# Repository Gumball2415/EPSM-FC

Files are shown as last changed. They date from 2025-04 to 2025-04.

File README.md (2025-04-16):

# EPSM-FC

Expansion Port Sound Module for the Famicom

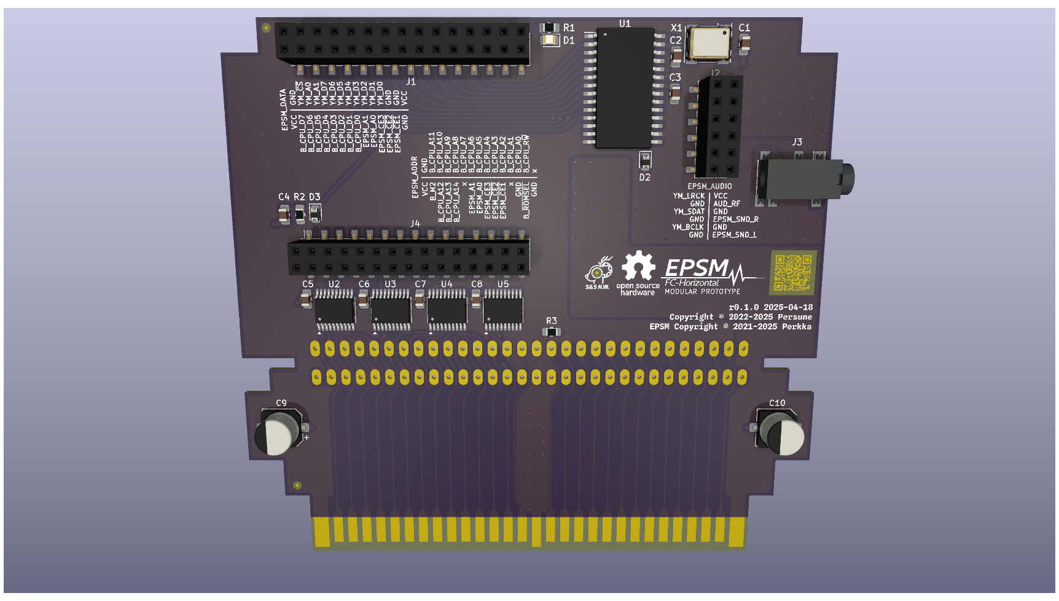
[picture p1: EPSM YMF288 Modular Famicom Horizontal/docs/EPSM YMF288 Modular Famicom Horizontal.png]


## About

Work in progress!!

This is a version of the EPSM ported for use with the Famicom.

The challenge with the Famicom version is that the device no longer has access
to the extra control signals on the NES expansion port. Most relevant, OUT1,
CPU_A15, and all the EXP pins. This project aims to solve this using extra logic
that can recreate the necessary signals for addressing the EPSM.

## License

This design is licensed under the TAPR Open Hardware License.\
For resale, please contact Pierre Althinsson (Perkka).

Original EPSM is Copyright (C) 2021-2025 Pierre Althinson.\
EPSM-FC is Copyright (C) 2022-2025 Persune.

## Usage

- [NESDev wiki](https://www.nesdev.org/wiki/Expansion_Port_Sound_Module)
- Also see [the original EPSM repo](https://github.com/Perkka2/EPSM/)

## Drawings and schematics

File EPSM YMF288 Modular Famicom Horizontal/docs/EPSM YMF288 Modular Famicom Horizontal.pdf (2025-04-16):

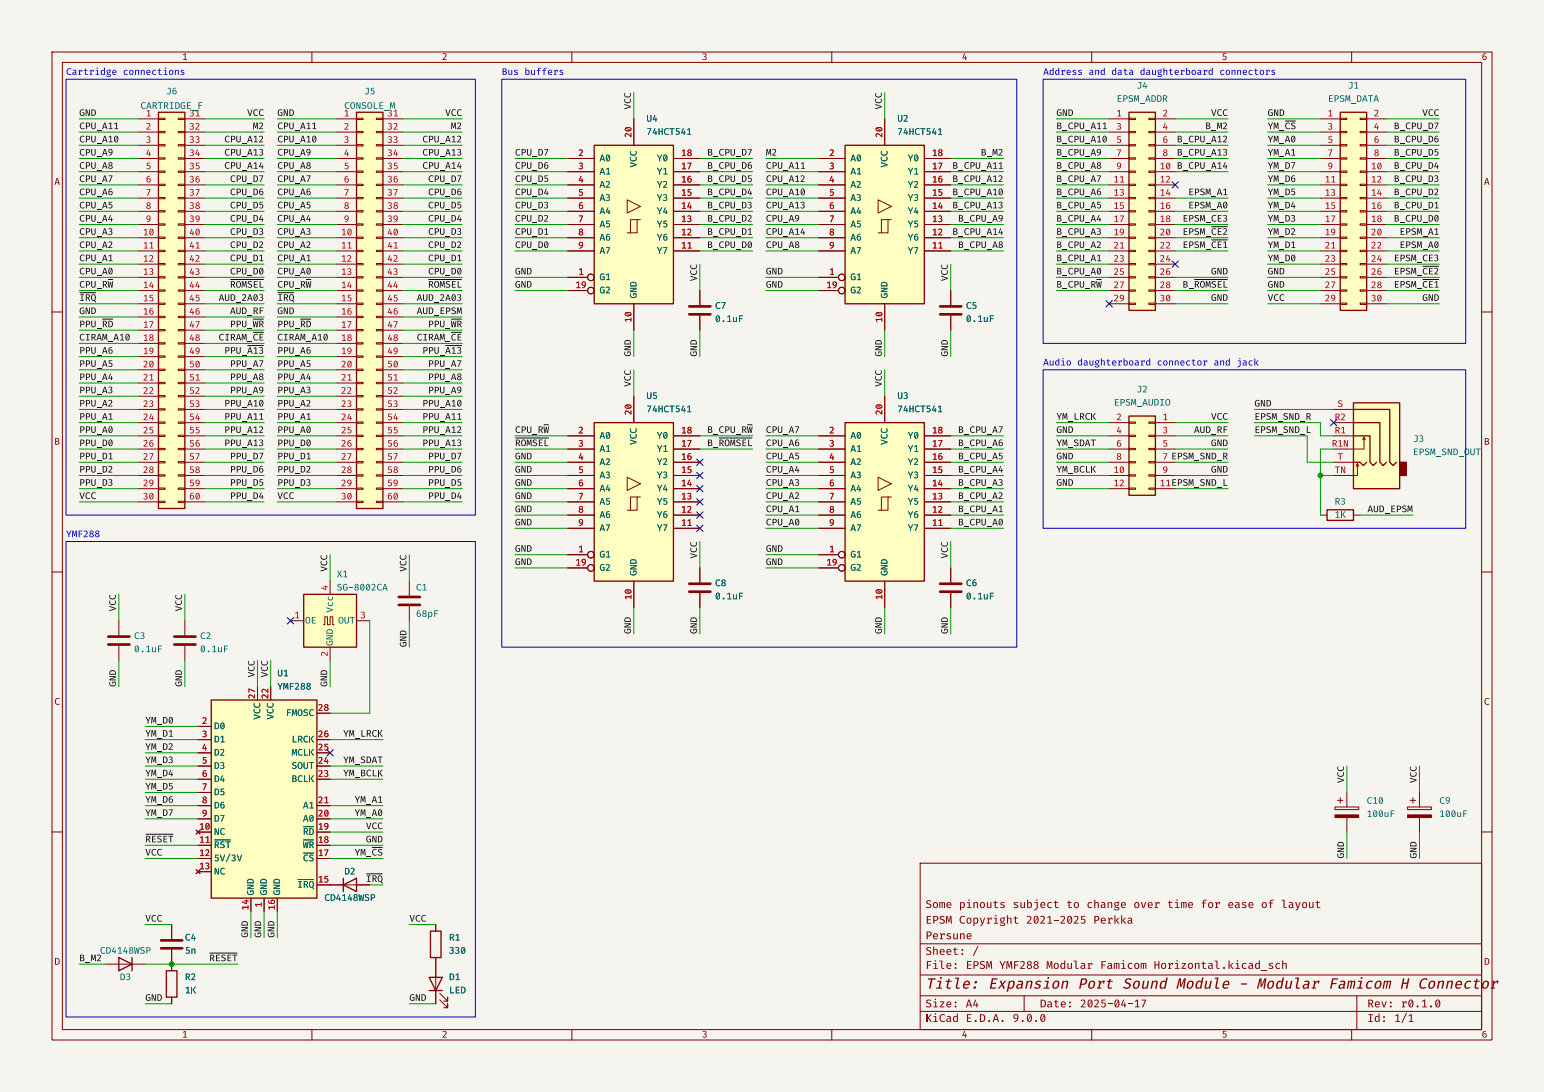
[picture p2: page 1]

20 ~{RD} 19 ~{WR} 18 ~{CS} 17 ~{IRQ}15 D0
YM_D4 YM_D5 YM_D2 YM_D3 VCC
~{RESET} YM_D6 YM_D7 VCC

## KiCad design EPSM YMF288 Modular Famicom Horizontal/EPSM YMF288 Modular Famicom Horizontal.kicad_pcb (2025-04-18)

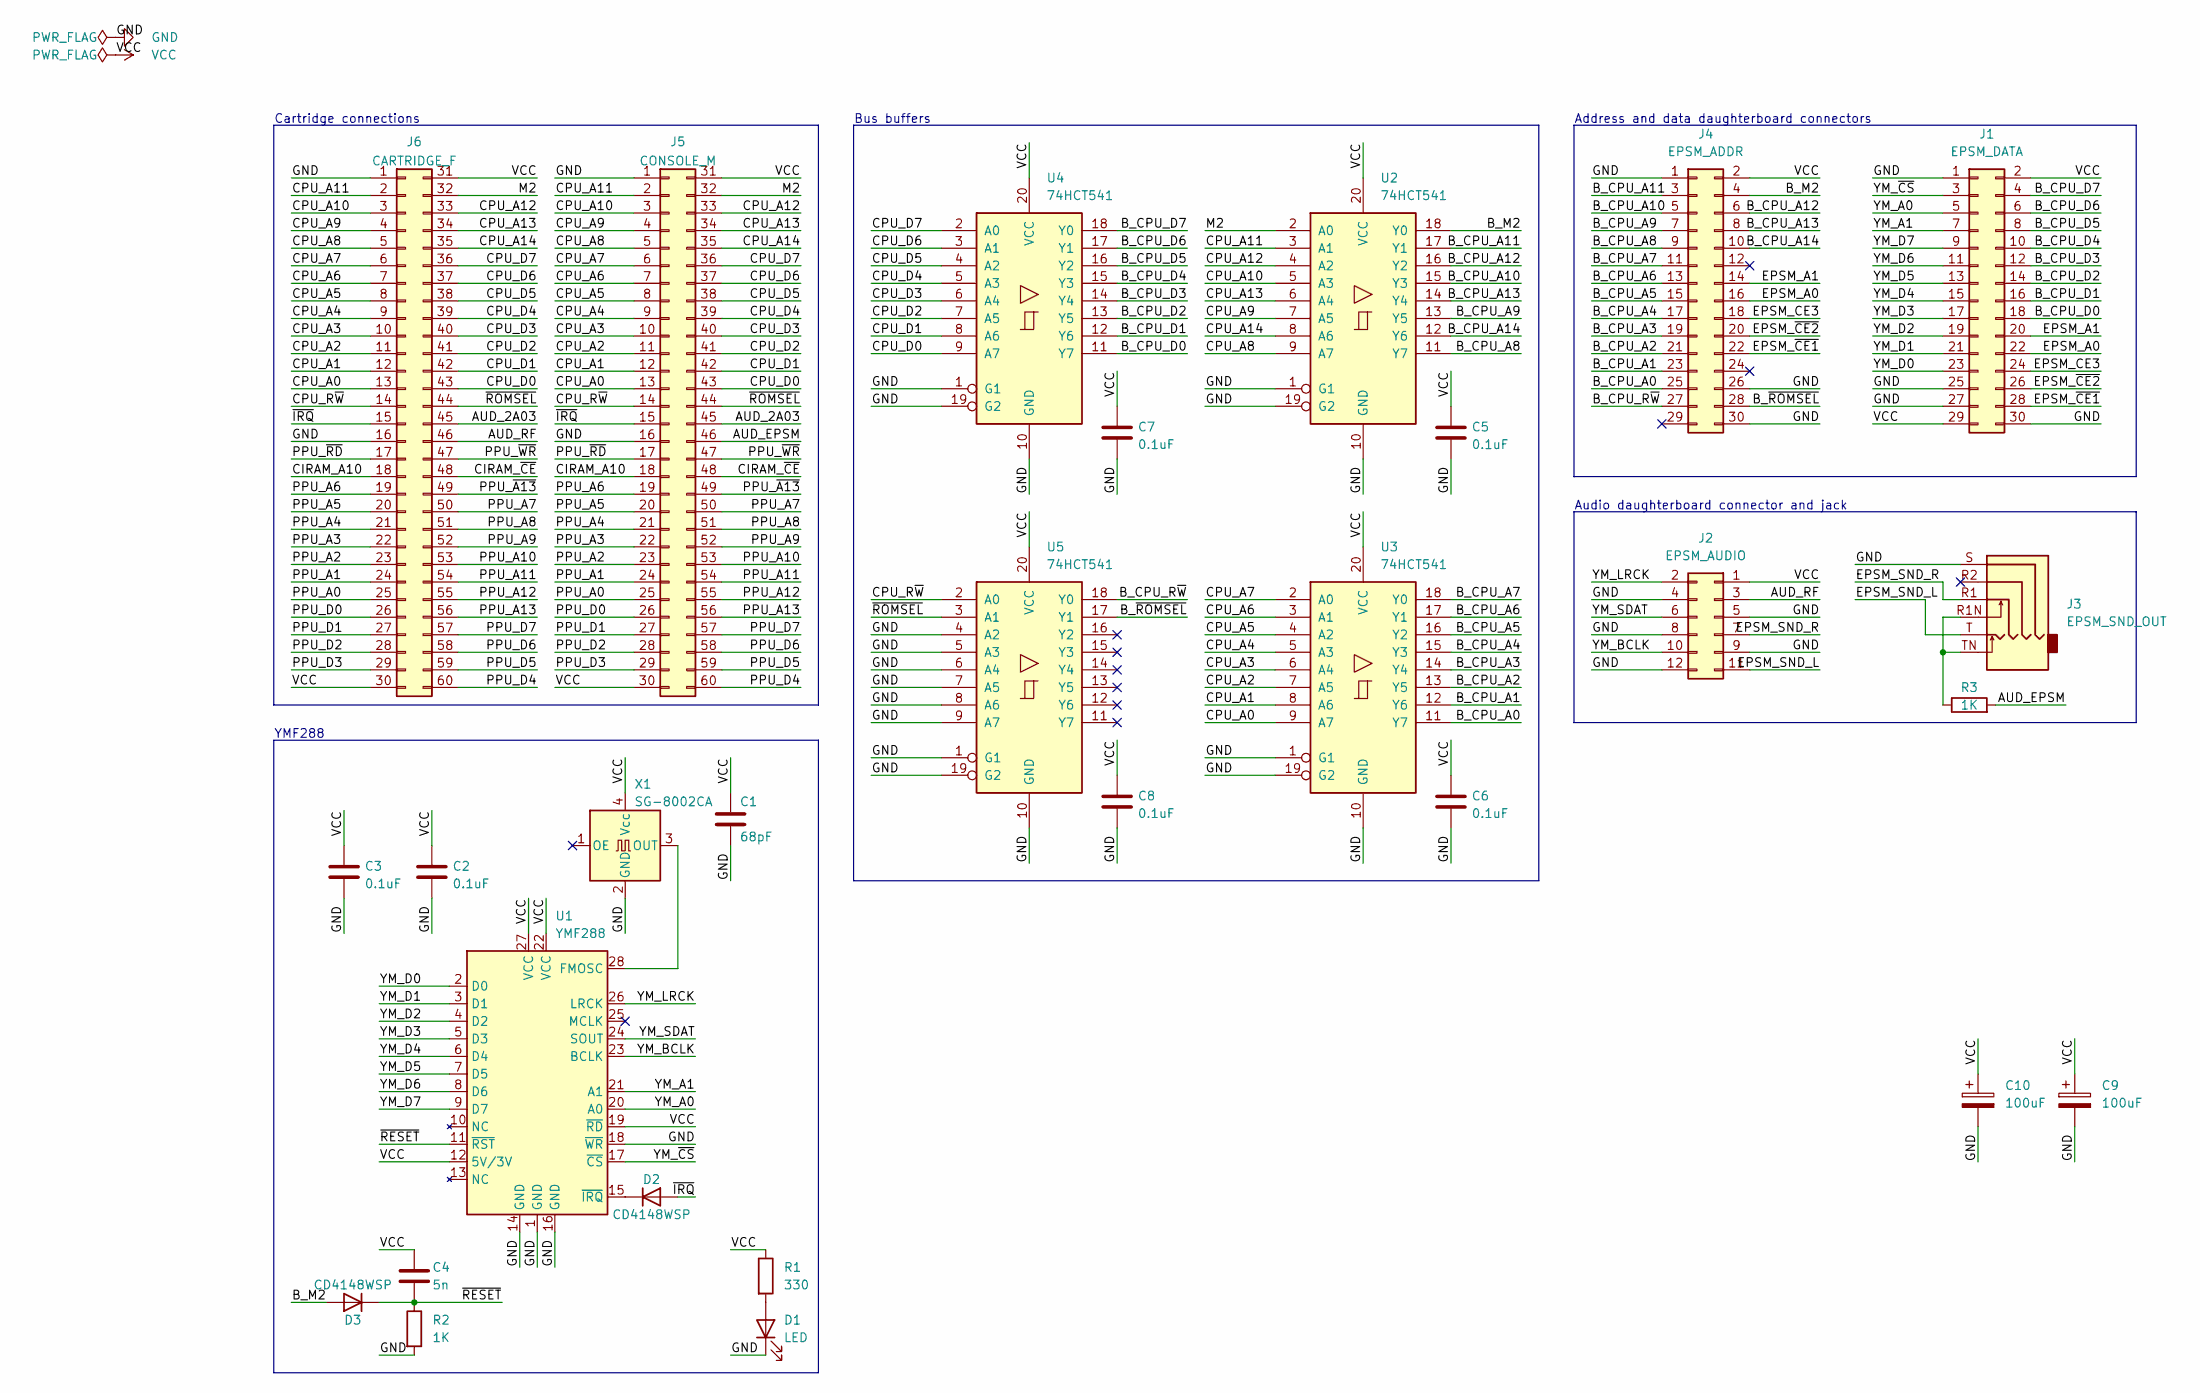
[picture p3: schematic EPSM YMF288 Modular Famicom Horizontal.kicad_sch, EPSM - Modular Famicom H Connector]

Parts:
C1: 68pF; C_0805_2012Metric_Pad1.18x1.45mm_HandSolder
C2, C3, C5, C6, C7, C8: 0.1uF; C_0805_2012Metric_Pad1.18x1.45mm_HandSolder
C4: 5n; C_0805_2012Metric_Pad1.18x1.45mm_HandSolder
C9, C10: 100uF; CP_Elec_6.3x5.4
D1: LED; LED_0805_2012Metric
D2, D3: CD4148WSP; D_0805_2012Metric
J1: EPSM_DATA; PinSocket_2x15_P2.54mm_Vertical_SMD
J2: EPSM_AUDIO; PinSocket_2x06_P2.54mm_Vertical_SMD
J3: EPSM_SND_OUT; Jack_3.5mm_PJ311_Horizontal
J4: EPSM_ADDR; PinSocket_2x15_P2.54mm_Vertical_SMD
J5: CONSOLE_M; HVC-ETROM-01
J6: CARTRIDGE_F; FC_CONN_F
R1: 330; R_0805_2012Metric_Pad1.20x1.40mm_HandSolder
R2, R3: 1K; R_0805_2012Metric_Pad1.20x1.40mm_HandSolder
U1: YMF288; SOP-28_8.4x18.1mm_P1.27mm
U2, U3, U4, U5: 74HCT541; TSSOP-20_4.4x6.5mm_P0.65mm
X1: SG-8002CA; Oscillator_SMD_Abracon_ASV-4Pin_7.0x5.1mm

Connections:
/AUD_2A03: J5.45, J6.45
/AUD_EPSM: J5.46, R3.2
/AUD_RF: J2.3, J6.46
/B_CPU_A0: J4.25, U3.11 (Y7)
/B_CPU_A1: J4.23, U3.12 (Y6)
/B_CPU_A2: J4.21, U3.13 (Y5)
/B_CPU_A3: J4.19, U3.14 (Y4)
/B_CPU_A4: J4.17, U3.15 (Y3)
/B_CPU_A5: J4.15, U3.16 (Y2)
/B_CPU_A6: J4.13, U3.17 (Y1)
/B_CPU_A7: J4.11, U3.18 (Y0)
/B_CPU_A8: J4.9, U2.11 (Y7)
/B_CPU_A9: J4.7, U2.13 (Y5)
/B_CPU_A10: J4.5, U2.15 (Y3)
/B_CPU_A11: J4.3, U2.17 (Y1)
/B_CPU_A12: J4.6, U2.16 (Y2)
/B_CPU_A13: J4.8, U2.14 (Y4)
/B_CPU_A14: J4.10, U2.12 (Y6)
/B_CPU_D0: J1.18, U4.11 (Y7)
/B_CPU_D1: J1.16, U4.12 (Y6)
/B_CPU_D2: J1.14, U4.13 (Y5)
/B_CPU_D3: J1.12, U4.14 (Y4)
/B_CPU_D4: J1.10, U4.15 (Y3)
/B_CPU_D5: J1.8, U4.16 (Y2)
/B_CPU_D6: J1.6, U4.17 (Y1)
/B_CPU_D7: J1.4, U4.18 (Y0)
/B_CPU_R~W: J4.27, U5.18 (Y0)
/B_M2: D3.2 (A), J4.4, U2.18 (Y0)
/B_~ROMSEL: J4.28, U5.17 (Y1)
/CIRAM_A10: J5.18, J6.18
/CIRAM_~CE: J5.48, J6.48
/CPU_A0: J5.13, J6.13, U3.9 (A7)
/CPU_A1: J5.12, J6.12, U3.8 (A6)
/CPU_A2: J5.11, J6.11, U3.7 (A5)
/CPU_A3: J5.10, J6.10, U3.6 (A4)
/CPU_A4: J5.9, J6.9, U3.5 (A3)
/CPU_A5: J5.8, J6.8, U3.4 (A2)
/CPU_A6: J5.7, J6.7, U3.3 (A1)
/CPU_A7: J5.6, J6.6, U3.2 (A0)
/CPU_A8: J5.5, J6.5, U2.9 (A7)
/CPU_A9: J5.4, J6.4, U2.7 (A5)
/CPU_A10: J5.3, J6.3, U2.5 (A3)
/CPU_A11: J5.2, J6.2, U2.3 (A1)
/CPU_A12: J5.33, J6.33, U2.4 (A2)
/CPU_A13: J5.34, J6.34, U2.6 (A4)
/CPU_A14: J5.35, J6.35, U2.8 (A6)
/CPU_D0: J5.43, J6.43, U4.9 (A7)
/CPU_D1: J5.42, J6.42, U4.8 (A6)
/CPU_D2: J5.41, J6.41, U4.7 (A5)
/CPU_D3: J5.40, J6.40, U4.6 (A4)
/CPU_D4: J5.39, J6.39, U4.5 (A3)
/CPU_D5: J5.38, J6.38, U4.4 (A2)
/CPU_D6: J5.37, J6.37, U4.3 (A1)
/CPU_D7: J5.36, J6.36, U4.2 (A0)
/CPU_R~W: J5.14, J6.14, U5.2 (A0)
/EPSM_A0: J1.22, J4.16
/EPSM_A1: J1.20, J4.14
/EPSM_CE3: J1.24, J4.18
/EPSM_SND_L: J2.11, J3.T
/EPSM_SND_R: J2.7, J3.R1
/EPSM_~CE1: J1.28, J4.22
/EPSM_~CE2: J1.26, J4.20
/M2: J5.32, J6.32, U2.2 (A0)
/PPU_A0: J5.25, J6.25
/PPU_A1: J5.24, J6.24
/PPU_A2: J5.23, J6.23
/PPU_A3: J5.22, J6.22
/PPU_A4: J5.21, J6.21
/PPU_A5: J5.20, J6.20
/PPU_A6: J5.19, J6.19
/PPU_A7: J5.50, J6.50
/PPU_A8: J5.51, J6.51
/PPU_A9: J5.52, J6.52
/PPU_A10: J5.53, J6.53
/PPU_A11: J5.54, J6.54
/PPU_A12: J5.55, J6.55
/PPU_A13: J5.56, J6.56
/PPU_D0: J5.26, J6.26
/PPU_D1: J5.27, J6.27
/PPU_D2: J5.28, J6.28
/PPU_D3: J5.29, J6.29
/PPU_D4: J5.60, J6.60
/PPU_D5: J5.59, J6.59
/PPU_D6: J5.58, J6.58
/PPU_D7: J5.57, J6.57
/PPU_~A13: J5.49, J6.49
/PPU_~RD: J5.17, J6.17
/PPU_~WR: J5.47, J6.47
/YM_A0: J1.5, U1.20 (A0)
/YM_A1: J1.7, U1.21 (A1)
/YM_BCLK: J2.10, U1.23 (BCLK)
/YM_D0: J1.23, U1.2 (D0)
/YM_D1: J1.21, U1.3 (D1)
/YM_D2: J1.19, U1.4 (D2)
/YM_D3: J1.17, U1.5 (D3)
/YM_D4: J1.15, U1.6 (D4)
/YM_D5: J1.13, U1.7 (D5)
/YM_D6: J1.11, U1.8 (D6)
/YM_D7: J1.9, U1.9 (D7)
/YM_LRCK: J2.2, U1.26 (LRCK)
/YM_SDAT: J2.6, U1.24 (SOUT)
/YM_~CS: J1.3, U1.17 (~CS)
/~IRQ: D2.2 (A), J5.15, J6.15
/~RESET: C4.1, D3.1 (K), R2.1, U1.11 (~RST)
/~ROMSEL: J5.44, J6.44, U5.3 (A1)
GND: C1.2, C2.1, C3.1, C5.1, C6.1, C7.1, C8.1, C9.2, C10.2, D1.1 (K), J1.1, J1.25, J1.27, J1.30, J2.4, J2.5, J2.8, J2.9, J2.12, J3.S, J4.1, J4.26, J4.30, J5.1, J5.16, J6.1, J6.16, R2.2, U1.1 (GND), U1.14 (GND), U1.16 (GND), U1.18 (~WR), U2.1 (G1), U2.10 (GND), U2.19 (G2), U3.1 (G1), U3.10 (GND), U3.19 (G2), U4.1 (G1), U4.10 (GND), U4.19 (G2), U5.1 (G1), U5.4 (A2), U5.5 (A3), U5.6 (A4), U5.7 (A5), U5.8 (A6), U5.9 (A7), U5.10 (GND), U5.19 (G2), X1.2 (GND)
unnamed: D1.2 (A), R1.2
unnamed: D2.1 (K), U1.15 (~IRQ)
unnamed: J3.R1N, J3.TN, R3.1
unnamed: U1.28 (FMOSC), X1.3 (OUT)
VCC: C1.1, C2.2, C3.2, C4.2, C5.2, C6.2, C7.2, C8.2, C9.1, C10.1, J1.2, J1.29, J2.1, J4.2, J5.30, J5.31, J6.30, J6.31, R1.1, U1.12 (5V/3V), U1.19 (~RD), U1.22 (VCC), U1.27 (VCC), U2.20 (VCC), U3.20 (VCC), U4.20 (VCC), U5.20 (VCC), X1.4 (Vcc)

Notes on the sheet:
Bus buffers
Address and data daughterboard connectors
YMF288
Audio daughterboard connector and jack
Cartridge connections

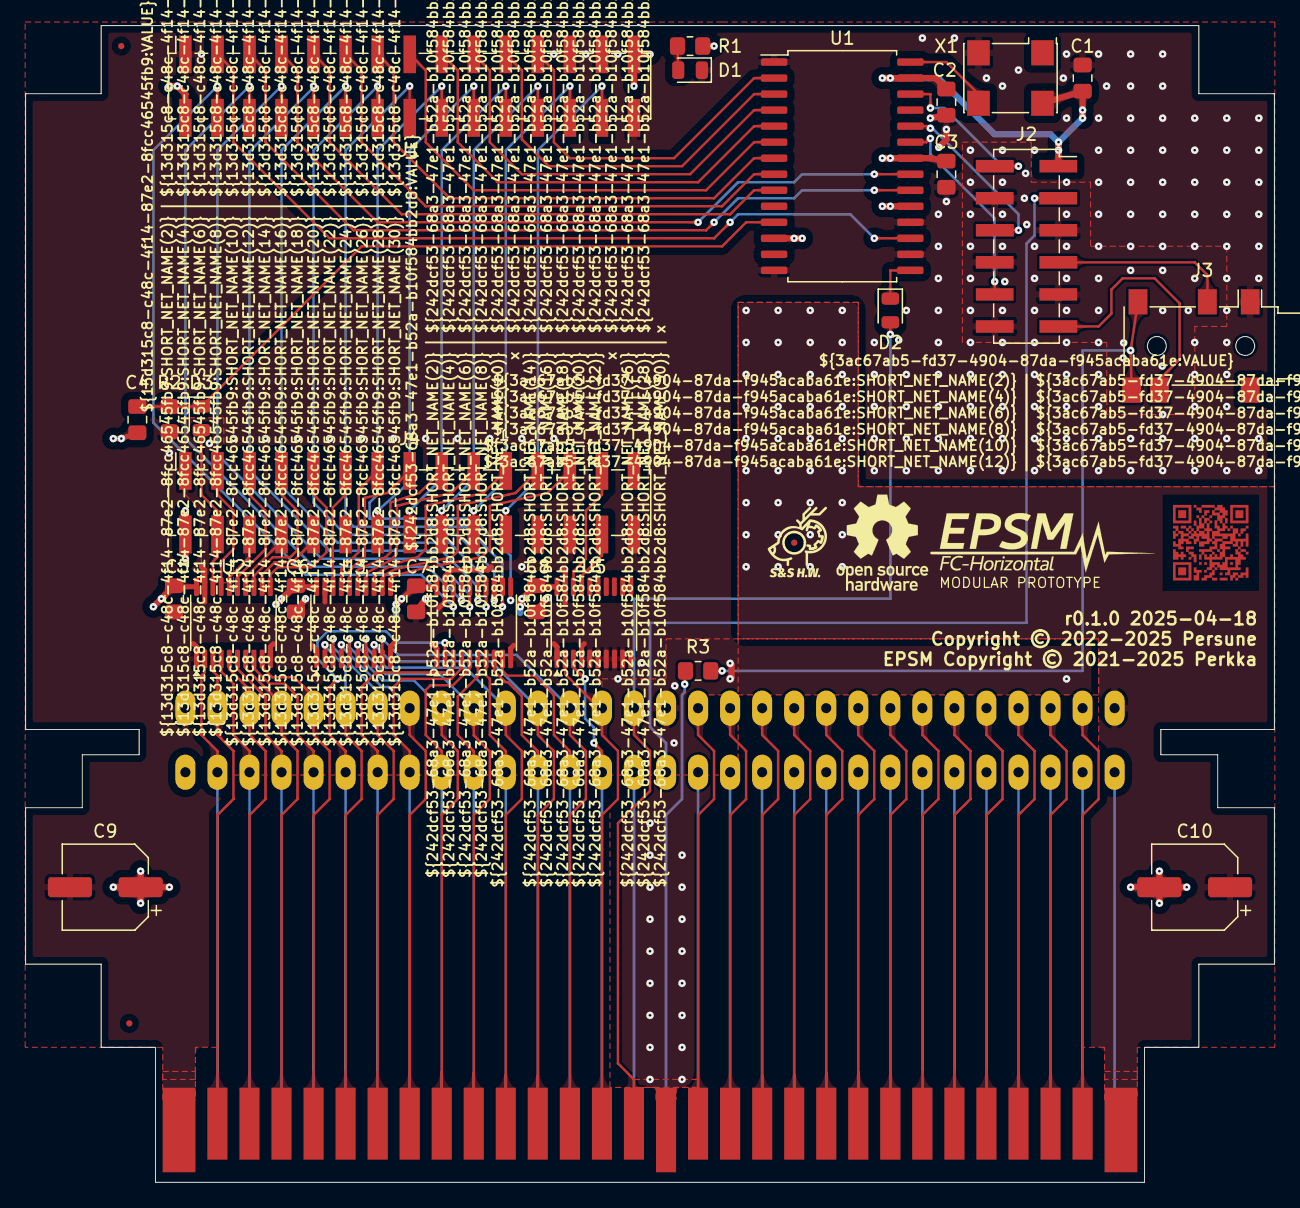
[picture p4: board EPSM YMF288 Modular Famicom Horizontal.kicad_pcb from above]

Board: 2 copper layers, 99.0 x 91.7 mm, 32 parts (1 on the bottom side), 111 nets.

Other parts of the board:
Ref**: Val**; EPSM_silkscreen
Ref**#2: Val**; oshw-logo
Ref**#3: Val**; qr
svg2mod: G***; maustech icon fiducial 0-50mm 1-50mm

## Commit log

2025-04-18 Adjust routing
    [EPSM YMF288 Modular Famicom Horizontal-rounded.kicad_pcb, EPSM YMF288 Modular Famicom Horizontal.kicad_pcb, EPSM YMF288 Modular Famicom Horizontal.kicad_sch]
2026-10-30 fix: Fix YMF288 wiring and reset
2026-11-05 feat: Add rounded PCB output

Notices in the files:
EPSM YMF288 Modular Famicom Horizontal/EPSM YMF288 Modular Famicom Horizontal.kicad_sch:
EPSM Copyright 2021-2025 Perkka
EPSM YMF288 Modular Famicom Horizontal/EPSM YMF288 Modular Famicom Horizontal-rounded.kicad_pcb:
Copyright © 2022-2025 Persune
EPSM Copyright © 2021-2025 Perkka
